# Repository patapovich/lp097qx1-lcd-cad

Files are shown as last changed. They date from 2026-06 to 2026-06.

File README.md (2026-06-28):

# LP097QX1-SPC1 — LCD mechanical CAD reference

Mounting/mechanical geometry for the **LG Display LP097QX1-SPC1** 9.7" 2048×1536 LCD
panel (as used in iPad 3/4), extracted from the datasheet **FRONT VIEW** drawing for
designing cases, bezels and mounts.

Geometry was **re-traced from a colour-cleaned render** of the FRONT VIEW: the
datasheet page is rasterized and every non-geometry marking (dimension lines,
dash-dot centerlines, green active-area reference, page header) is stripped *by
colour*, leaving only the black/grey object outline. The outline, 4 lug ears and
holes are then traced from that clean image and self-calibrated to the
167.12 × 208.88 outline. Hole centers cross-check against an independent
dimension-line calibration to **< 0.1 mm**.

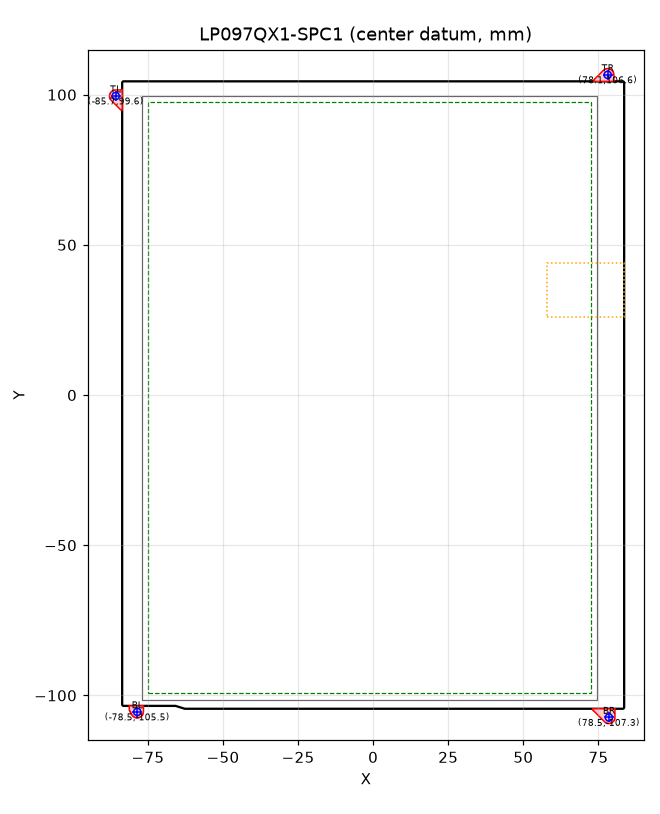
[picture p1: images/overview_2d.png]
2D overview


## Key dimensions (mm)

Datum = module-outline **center**, X → right, Y → up (front view as drawn).

| feature | size (W × H) | center offset | notes |
|---|---|---|---|
| Module outline | 167.12 × 208.88 (±0.5) | (0, 0) | thickness **2.60 max**; corners **R0.5**; **bottom-left non-square**: bottom edge raised to Y=−103.48 for X∈[−83.56,−65.8], ramps to full bottom (−104.44) by X=−62.7 |
| Bezel / polarizer | 151.608 × 201.01 | (−1.27, −0.86) | visible glass window |
| Active area | 147.456 × 196.608 | (−1.30, −0.89) | **not centered** |

### 4 mounting-lug holes — ⌀2.4 mm

| lug | X | Y | ear |
|---|---|---|---|
| TL | −85.71 | +99.55 | teardrop, points **left** (hole outside left edge) |
| TR | +78.07 | +106.59 | gusset, points **up** (hole outside top edge) |
| BL | −78.55 | −105.50 | teardrop, points **down** |
| BR | +78.48 | −107.34 | teardrop, points **down** |

> ⚠️ The lug layout is **asymmetric** (not a mirror set). Lugs protrude 3–5 mm past the
> 167.12 × 208.88 outline — your case must clear them.

**Z plane:** all 4 ears sit on the **front** (screen) face, Z 2.30–2.60 (thin 0.30 mm tabs).
The **rear FPC connector** is a keep-out boss on the **right long edge** (Y ≈ +26..+44),
protruding **~1.2 mm behind** the rear face (Z −1.20..0) — footprint approximate.

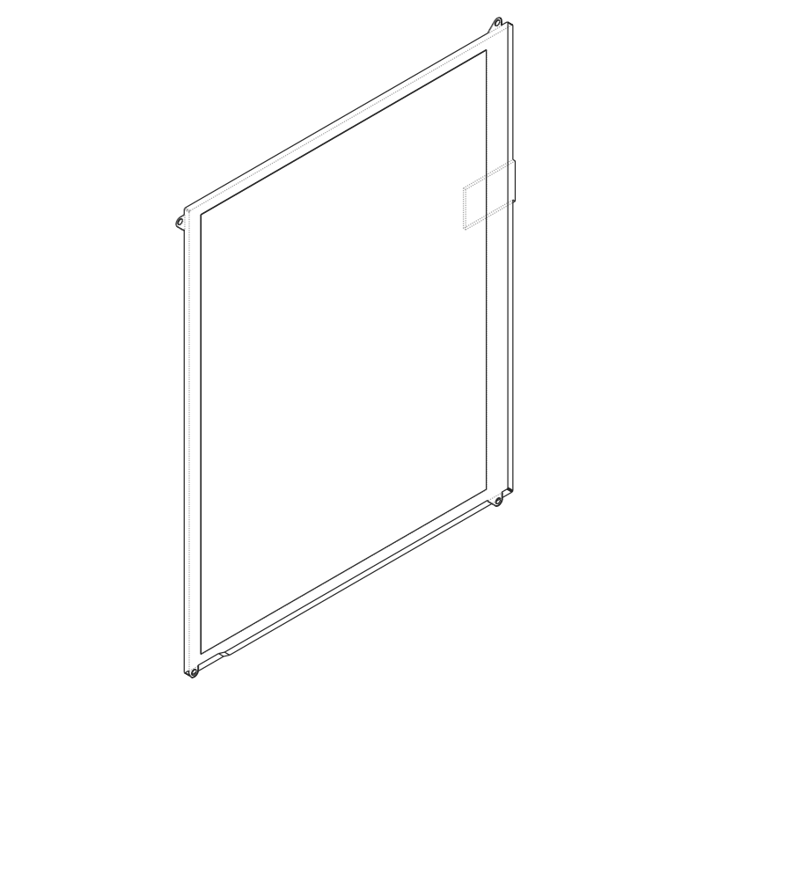
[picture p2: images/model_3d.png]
3D model


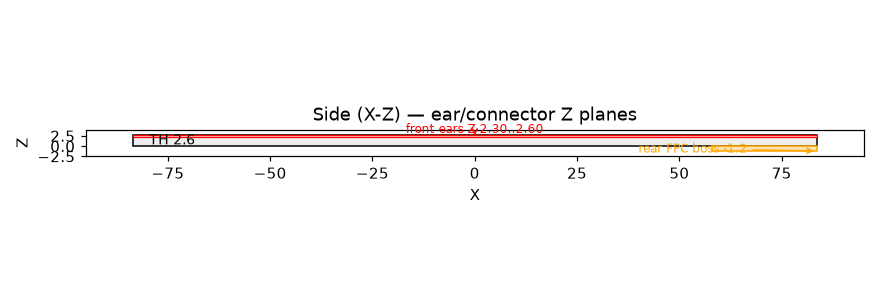
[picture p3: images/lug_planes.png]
lug planes


## Files

| file | description |
|---|---|
| `lcd_panel.step` | 3D solid: body + exact teardrop/gusset lug ears + ⌀2.4 holes + active-area pocket |
| `lcd_panel.stl` | mesh version of the above |
| `lcd_panel.scad` | parametric OpenSCAD source (all dims as variables) |
| `lcd_centerdatum.dxf` | 2D top view, origin = outline center, Y up |
| `lcd_cornerdatum.dxf` | 2D top view, origin = outline top-left, Y down (drawing convention) |
| `lcd_sideprofile.dxf` | side (Z) section: thickness 2.60, lug front plane, active recess |
| `lcd_lugs.csv` | hole coordinates, both datums |
| `lcd_reference.txt` | full numeric reference |
| `geometry.json` | **single source of truth** — clean-traced outline, ears, holes, bezel, Z, connector |
| `build_step.py` | builds the STEP/STL from `geometry.json` (needs cadquery) |
| `make_clean.py` | strips markings by colour + rasterizes the clean render |
| `trace2..6.py`, `geom.py` | trace pipeline (silhouette → edges → ears → holes → `geometry.json`) |
| `make_outputs.py` | regenerates the DXF/SCAD/CSV/reference/images |
| `verify.py` | overlays `geometry.json` back on the clean render |
| `bracket_top.step` / `.stl` | top photo-frame mounting bracket (3D print) |
| `bracket_bottom.step` / `.stl` | bottom photo-frame mounting bracket (3D print) |
| `bracket_top_thin.stl` / `bracket_bottom_thin.stl` | 5 mm-thick test-print variants (same XY/fit) |
| `build_brackets.py` | builds the two brackets from `geometry.json` + frame params (cadquery) |
| `brackets.scad` | parametric OpenSCAD source for the brackets |
| `verify_brackets.py` | assembly + side-section check images for the brackets |
| `passepartout.dxf` | mat cut lines (BOARD / WINDOW_SCREEN / WINDOW_GLASS layers) |
| `passepartout.py` | builds the mat drawing + DXF (180×240, 45° bevel window = screen) |
| `LP097QX1-SPC1.pdf` | source datasheet (© LG Display) |

DXF layers: `OUTLINE`, `BEZEL`, `ACTIVE`, `HOLES`, `HOLE_CENTERS`, `EARS`, `CONNECTOR`.

### Lug ear shapes
Traced silhouettes (red) + ⌀2.4 holes (green) over the colour-cleaned drawing:

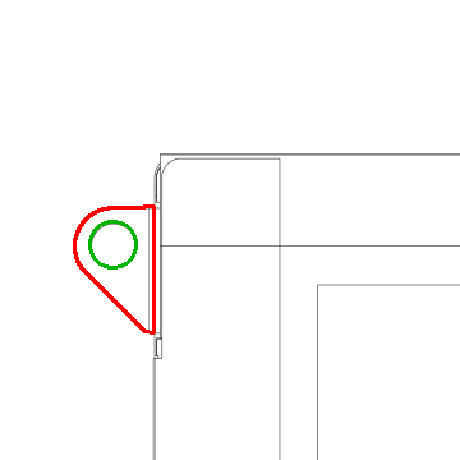
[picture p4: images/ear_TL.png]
ear TL
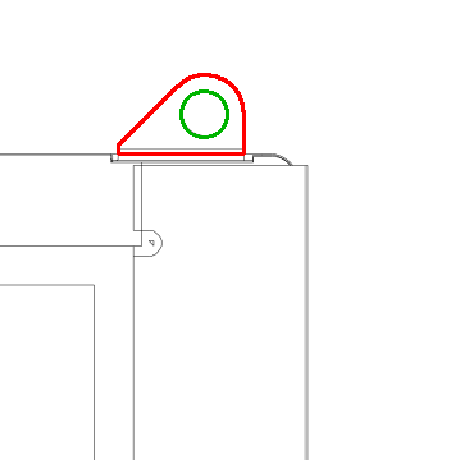
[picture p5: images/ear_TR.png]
ear TR
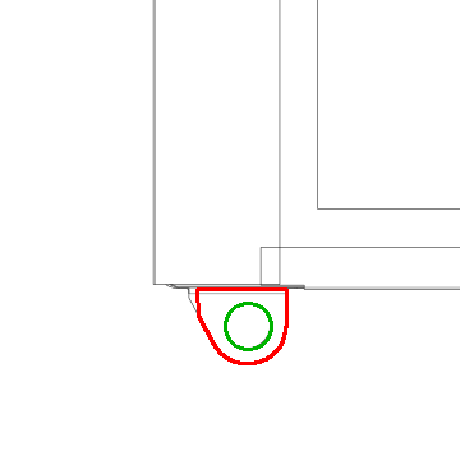
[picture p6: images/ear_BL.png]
ear BL
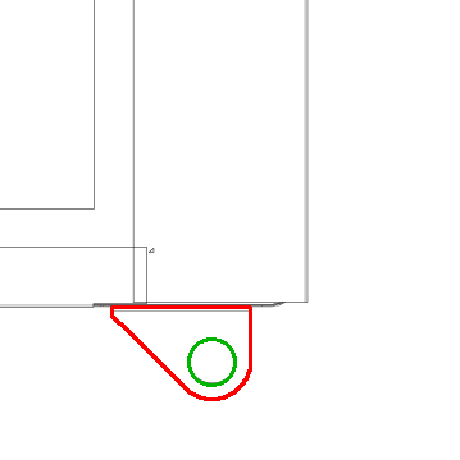
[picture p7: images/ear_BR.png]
ear BR
   

Lugs are **thin flat sheet-metal tabs (0.30 mm)** — not full-thickness — all on the
**front** (screen-side) face.

## Regenerate the 3D model

```bash
python3 -m venv cqenv
cqenv/bin/pip install cadquery cairosvg opencv-python-headless scipy
cqenv/bin/python build_step.py      # geometry.json -> lcd_panel.step + lcd_panel.stl
cqenv/bin/python make_outputs.py    # -> DXF / SCAD / CSV / reference / images
```

Re-trace from the PDF: `make_clean.py` → `trace2..6.py` → `geom.py` (writes `geometry.json`),
then `verify.py` overlays the result on the clean render. Or render the parametric source with
OpenSCAD: `openscad -o lcd_panel.stl lcd_panel.scad`.

## Photo-frame mounting brackets

Two **3D-printable back-press brackets** that hold the panel **centered in a photo frame** whose
inner cavity is **182 (W) × 242 (H) mm**. They sit on the panel's **short sides** (top + bottom),
friction-fit between the frame side walls. There is **no lip in front of the panel** — the screen
sits **flat on the frame glass**; the panel slides into a **2.75 mm slot** (2.60 LCD + 0.15) with the
rear shelf **behind** it, and the frame backing pushes the bracket so the shelf presses the LCD onto
the glass.

They **center the VIEW (active) area, not the outline.** The active area is offset from the
outline center by (−1.30, −0.89), so the panel is shifted (+1.30, +0.89) and the brackets are
sized to suit — the image lands in the frame center.

| | value |
|---|---|
| Frame inner cavity | 182 × 242 mm |
| Top-bracket gap (Y-depth) | **15.67 mm** |
| Bottom-bracket gap (Y-depth) | **17.45 mm** |
| Left / right gap (open, no bracket) | 8.74 / 6.14 mm |
| Bracket length (X, friction) | 181.8 mm (182 − 0.2) |
| Total thickness (Z) | 15.0 mm (screen on glass; rear shelf 2.75 → 15) |
| Panel slot (Z) | 2.75 mm = 2.60 LCD + 0.15 clearance; shelf sits **behind** the LCD |
| Rear shelf overhang onto border | 3.0 mm (clear of the active area) |

Check: 15.67 + 208.88 + 17.45 = 242.0 ✓. The lug ears are on the LCD **front** (recessed ~0.25 mm),
so each bracket's **ear-clearance pockets are cut on the front (glass) face** (top: TL+TR, bottom:
BL+BR). This **shape-keys** the part — it only seats with the ears in the front pockets (glass side),
which keeps the rear shelf behind the LCD, pressing it **from behind onto the glass**. The two
brackets are **different parts** (gaps and ear pockets differ).

**Thin test-print variants** (`bracket_top_thin.stl`, `bracket_bottom_thin.stl`, Z = 5 mm) have the
same XY/fit/slot/ear pockets — print one fast/cheap to check fit + orientation before the full 15 mm
part. Ear pockets are placed at each tab's **actual** position (the asymmetric layout: TL left-edge,
TR top-edge, BL/BR bottom-edge), with **1.5 mm clearance** all round — see the coverage check below.
Pockets + outline are **`MIRROR_X`-handed to match the physical panel** (see Handedness above).

Each bracket's total depth into the cavity is the end-gap **plus** the 3 mm shelf overhang behind the
LCD border (top 15.67+3.0, bottom 17.45+3.0), all behind the screen — the active area stays clear.

**Handedness:** the datasheet **FRONT VIEW is mirrored left-right vs the physical panel**, so the
brackets are built with **`MIRROR_X=True`** to match the real part. Front view (screen toward you):
the prominent angled lug is at the **top-right**, the single up-poking lug at the top-left, two lugs
on the bottom edge. (Set `MIRROR_X=False` to follow the raw datasheet handedness instead.)

### Orientation (important)
The part is nearly symmetric front-to-back, so it has an explicit key: the flat rear face is
**debossed "BACK"**. That face goes against the **frame backing**; the opposite face — with the open
slot + ear pockets — goes against the **glass / LCD**. The rear shelf then sits behind the LCD and the
frame backing presses it **from behind onto the glass**.

- **Print** the flat **"BACK"** face on the bed (slot + pockets facing up) → the rear-shelf overhang
  prints support-free. The bed face is the frame-backing face.
- **Assemble:** frame face-down on the glass; LCD in screen-first (rests on glass); push each bracket
  into its end gap **pocket/open face toward the glass** (the "BACK" deboss faces out, toward you) so
  the rear shelf sits behind the LCD edge; close the frame back — its clamping seats the LCD on the glass.

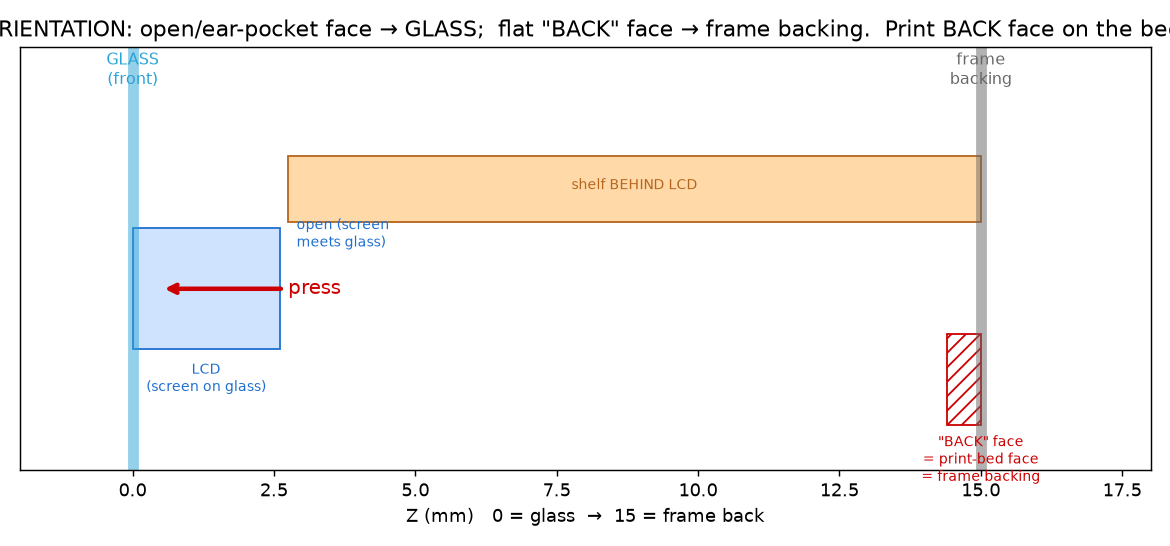
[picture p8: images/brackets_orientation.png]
bracket orientation

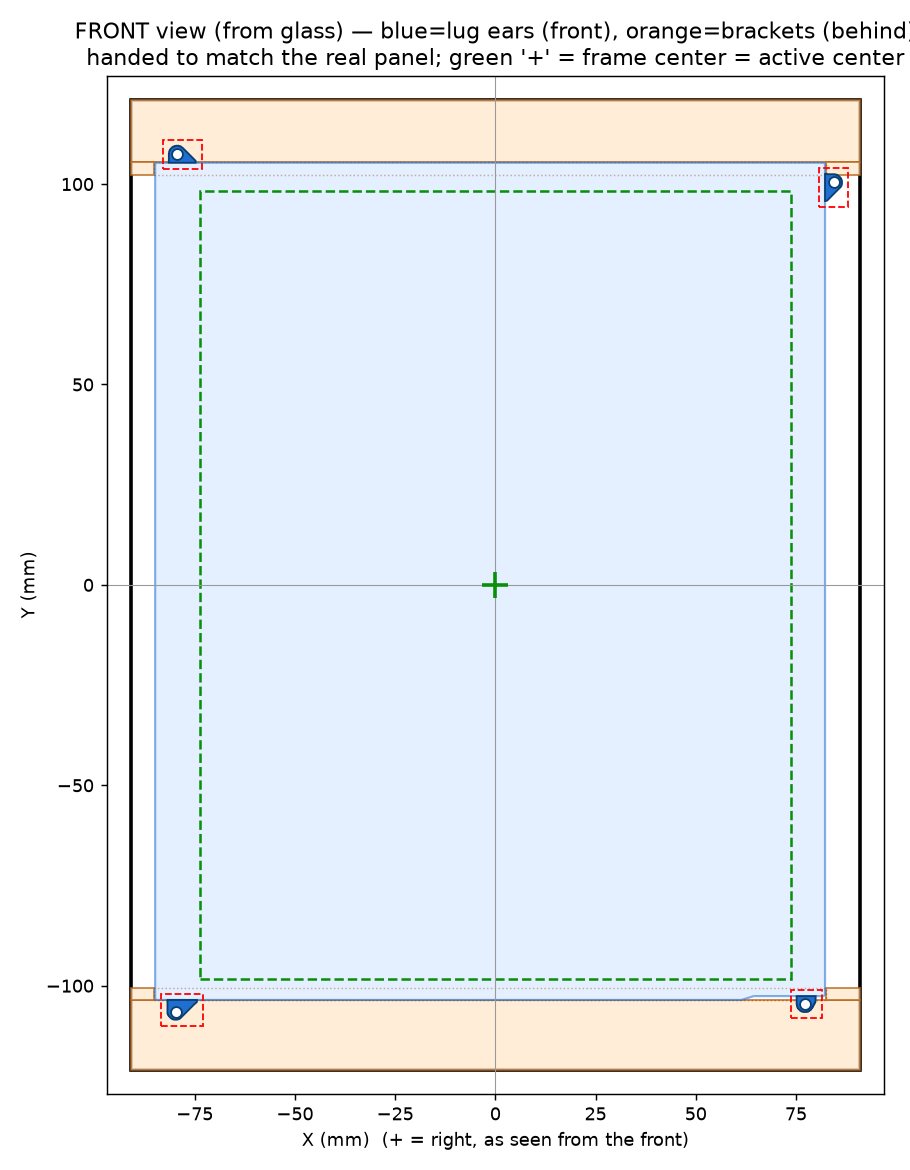
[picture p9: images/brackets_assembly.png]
bracket assembly

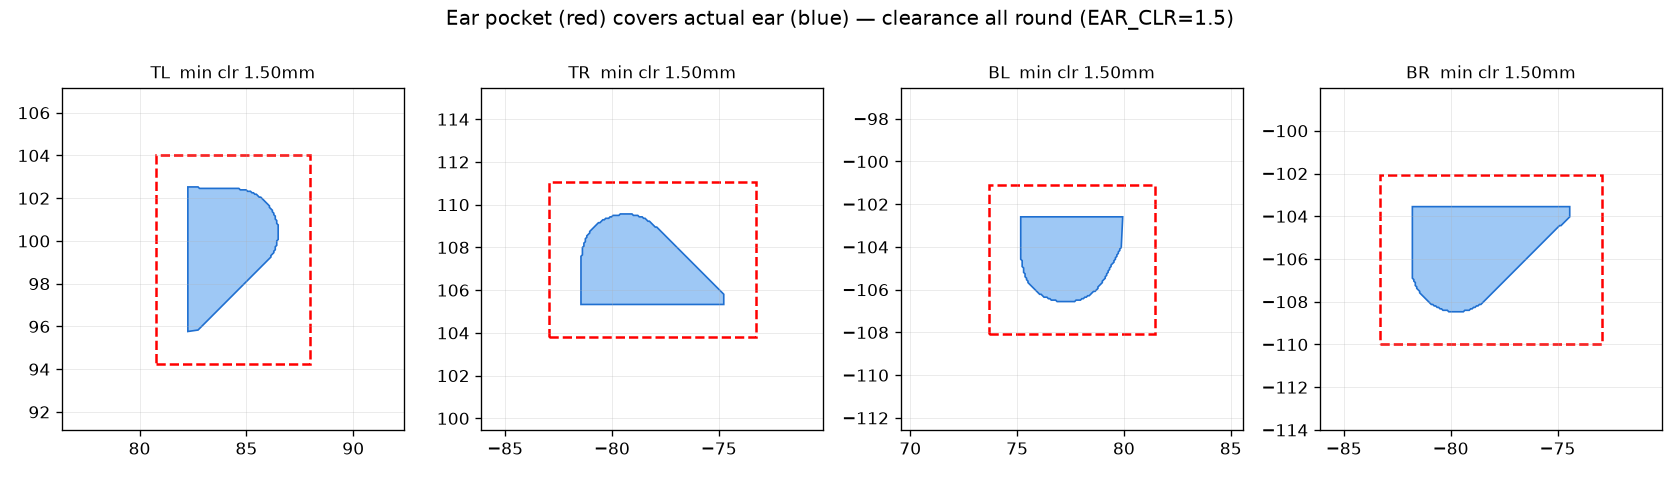
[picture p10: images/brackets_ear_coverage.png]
ear pocket coverage

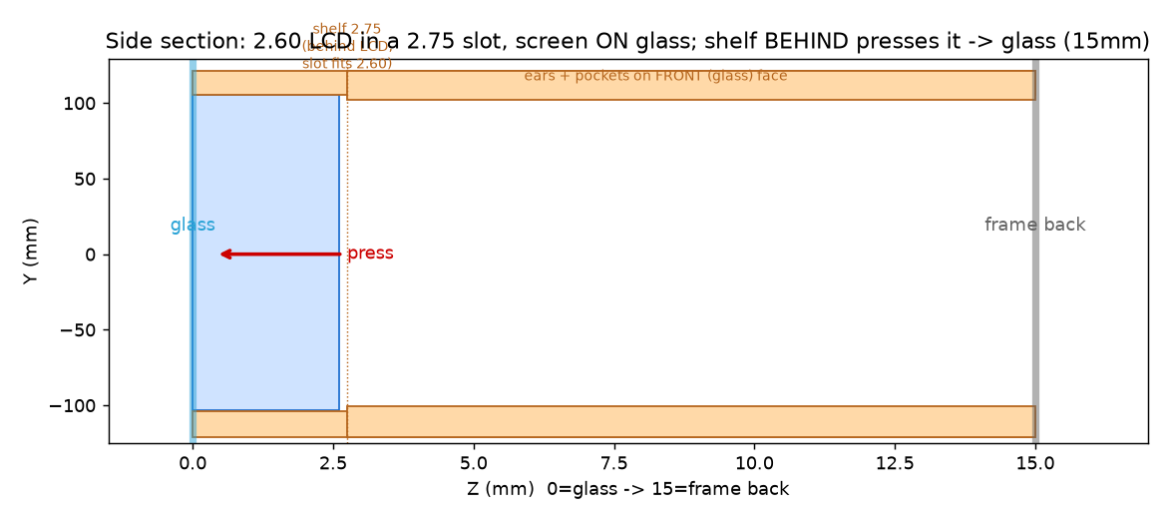
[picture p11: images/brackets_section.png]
bracket section


**Print:** PLA/PETG, lay flat — no supports. **Tune the fit** at the top of `build_brackets.py` /
`brackets.scad`: `FIT_CLR` (frame friction), `SEAT_CLR`/`POCKET_CLR` (panel play), `SLOT_CLR`
(panel slot Z — lower for tighter glass contact, raise if the LCD is tight), `EAR_Z` (front ear-pocket
depth), `LIP_Y` (rear-shelf grip), `MIRROR_X` (flip handedness), `LABEL` (the "BACK" deboss).
`VIEW_CENTER=False` centers the outline instead (equal 16.56 mm gaps). (Assembly + print orientation
are covered in **Orientation** above.)

```bash
cqenv/bin/python build_brackets.py     # -> bracket_top/bottom .step + .stl
cqenv/bin/python verify_brackets.py    # -> images/brackets_assembly.png + brackets_section.png
# or parametric: openscad -o bracket_top.stl -D 'part="top"' brackets.scad
```

## Passe-partout (mat window)

A **180 × 240 × 1.4 mm** mat with a centred **45° bevel** window that reveals only the **active
screen** (147.456 × 196.608). The brackets centre the active area at the frame centre, so the window
is **centred** in the board (symmetric — equal borders).

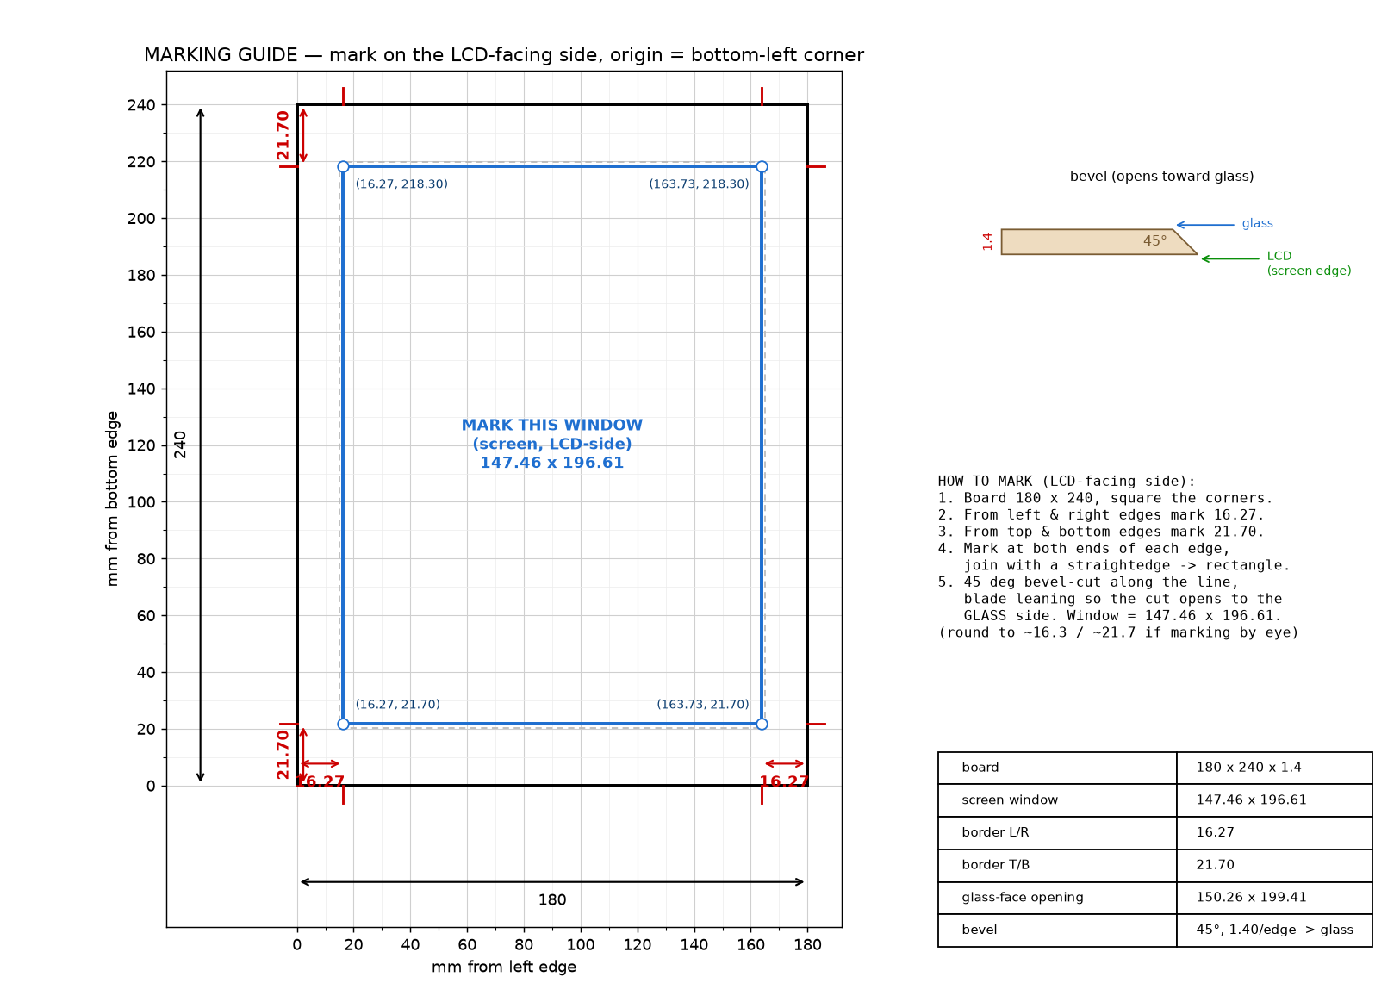
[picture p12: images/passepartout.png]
passe-partout


**Bevel opens toward the glass/viewer** — the screen-sized (limiting) edge is on the **LCD-facing
(back) face**, sitting right at the screen plane; the 45° bevel flares **1.4 mm/edge toward the glass**
so the white bevel faces you.

| feature | mm |
|---|---|
| Board (outer) | 180 × 240 × 1.4 |
| **Screen window** (visible crop, on LCD-side face) | **147.46 × 196.61** (= active screen) |
| LCD-face border — L/R, T/B | **16.27**, **21.70** |
| Glass-face opening (larger, bevel mouth) | 150.26 × 199.41 |
| Glass-face border — L/R, T/B | 14.87, 20.30 |
| Bevel | 45°, run 1.40 mm/edge, opens toward glass |

**Hand-marking** (`images/passepartout.png` is a ruler/pencil guide): on the LCD-facing side, from
**each** edge measure **16.27 mm** (left/right) and **21.70 mm** (top/bottom), mark at both ends of
every edge, join with a straightedge → the 147.46 × 196.61 rectangle, then 45° bevel-cut. Window
corners from the bottom-left corner: **(16.27, 21.70)**, **(163.73, 21.70)**, **(16.27, 218.30)**,
**(163.73, 218.30)**.

- The **screen-sized opening is on the LCD side** (147.46 × 196.61) and crops exactly to the screen;
  the bevel widens to **150.26 × 199.41** at the glass face. White bevel faces the viewer.
- Manual cutter: cut so the **small (screen-sized) opening is on the LCD-facing side**; the 45° bevel
  mouth opens toward the glass. `WINDOW_SCREEN` in the DXF is the crop edge, `WINDOW_GLASS` the mouth.
- Set `BEVEL_TOWARD="lcd"` in `passepartout.py` for the standard picture-mat direction (screen edge on
  the glass face instead). `OVERLAP=1.0` covers ~1 mm of the screen edge (no bezel sliver).
- Board 180 × 240 sits in the 182 × 242 frame with ~1 mm clearance/side — keep it centred so the
  window lines up with the (centred) screen.

## Accuracy

- Outline = datasheet nominal (167.12 × 208.88); model self-calibrated to it.
- Hole centers: ≈ ±0.05 mm relative, ≈ ±0.1 mm vs the independent dimension-line calibration.
- Ear silhouettes are traced from the clean render (≈ ±0.1 mm, drawing-scale limit).
- Datasheet's own outline tolerance is ±0.5 mm.
- Lug ears are **thin flat sheet-metal tabs (0.30 mm)**, all on the **front** (screen) face
  (Z 2.30..2.60), confirmed against the physical part.

## Source

Datasheet: LG Display LP097QX1-SPC1, mirrored at
<http://mikesmods.com/mm-wp/wp-content/uploads/2013/04/LP097QX1-SPC1.pdf>
(FRONT VIEW, printed page 16/28). The PDF is © LG Display, included here for reference.

Extracted geometry and CAD files in this repo are provided as-is, no warranty — verify
against the datasheet before manufacturing.

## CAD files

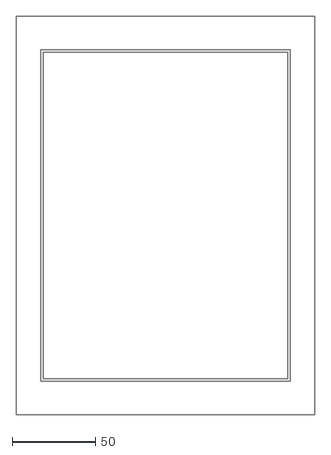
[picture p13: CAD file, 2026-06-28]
passepartout.dxf
180.0 x 240.0

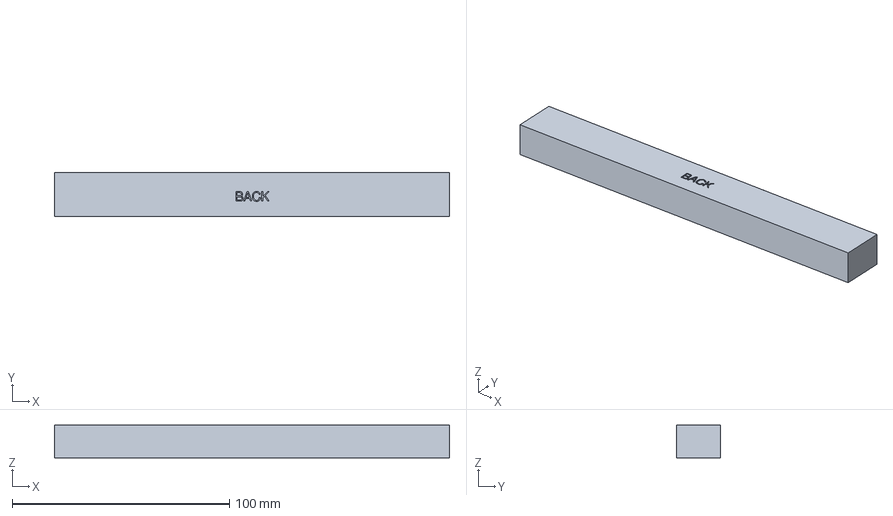
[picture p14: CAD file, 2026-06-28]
bracket_bottom.step
181.8 x 20.5 x 15.0 mm

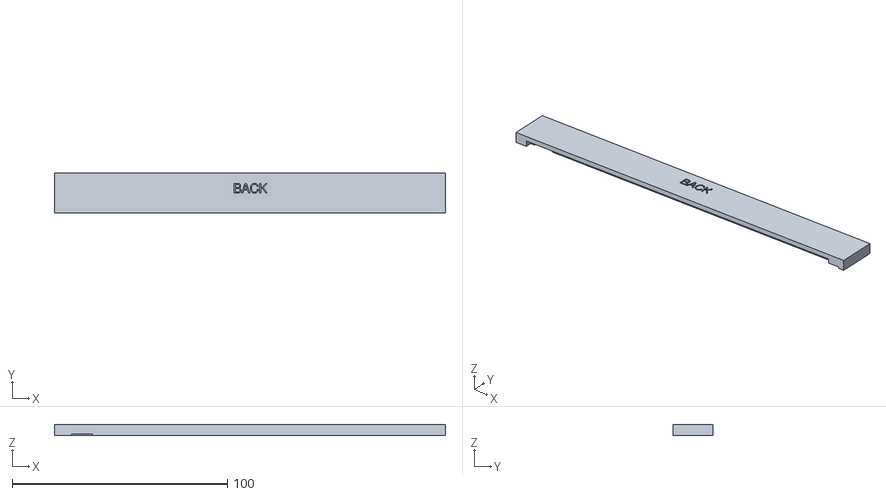
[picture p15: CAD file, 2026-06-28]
bracket_top_thin.stl
181.8 x 18.7 x 5.00

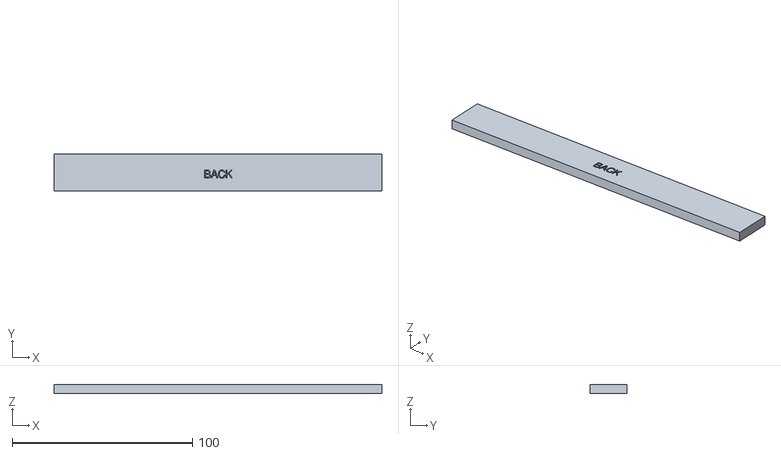
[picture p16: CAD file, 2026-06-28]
bracket_bottom_thin.stl
181.8 x 20.4 x 5.00

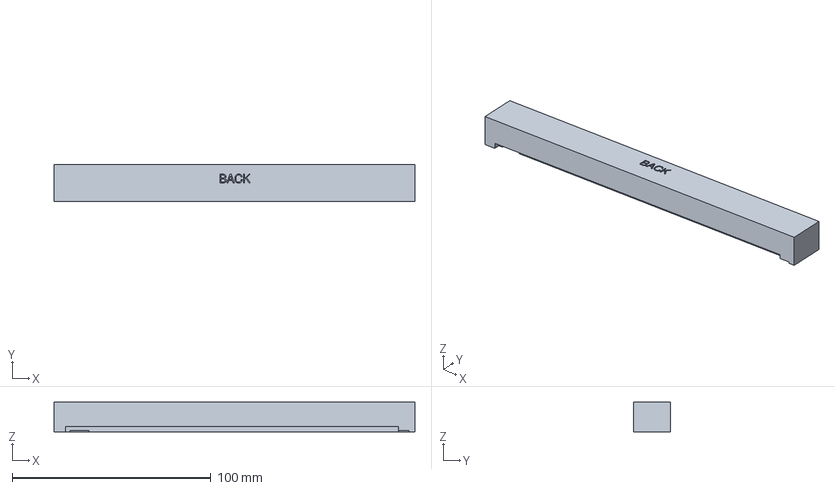
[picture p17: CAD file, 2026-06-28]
bracket_top.step
181.8 x 18.7 x 15.0 mm

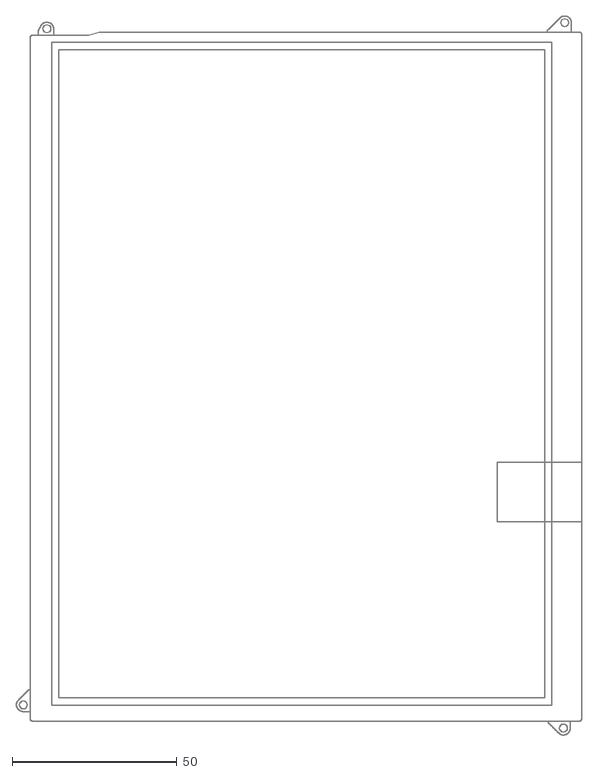
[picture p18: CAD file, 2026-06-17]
lcd_cornerdatum.dxf
171.3 x 218.0

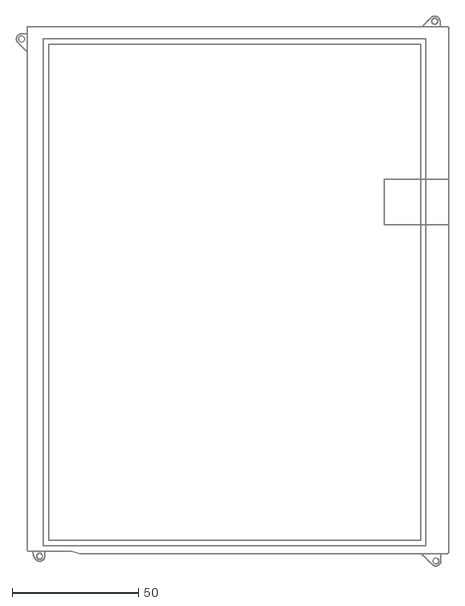
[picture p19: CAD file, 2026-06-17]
lcd_centerdatum.dxf
171.3 x 218.0

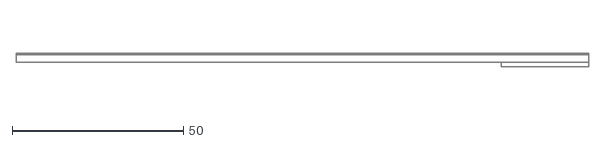
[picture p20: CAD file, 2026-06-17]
lcd_sideprofile.dxf
167.1 x 3.80

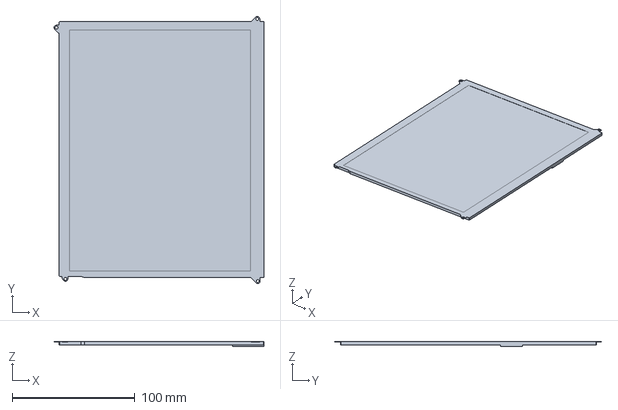
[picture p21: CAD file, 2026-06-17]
lcd_panel.step
171.3 x 218.0 x 3.80 mm

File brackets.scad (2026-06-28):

// Photo-frame brackets for the LP097QX1-SPC1 LCD — parametric OpenSCAD twin of build_brackets.py
// Two L / back-press brackets on the panel's SHORT sides (top + bottom). Friction-fit in the frame.
// No front lip: the screen sits flat on the glass; the panel slot = panel_th + slot_clr and the rear
// shelf sits BEHIND the panel, so the frame backing pushes the bracket -> LCD onto the glass (push
// from behind). Centers the VIEW (active) area. Lug ears are on the LCD FRONT (recessed ~0.25mm) ->
// shallow ear pockets on the front face, which shape-keys the part (only seats ears-toward-glass).
// Frame coords: origin = frame center, X right, Y up, Z=0 glass -> +Z into cavity.
//   render: openscad -o bracket_top.stl -D part=\"top\" brackets.scad
//   thin test print: add -D total_z=5
part = "both";        // "both" | "top" | "bottom"

/* ---- frame + panel ---- */
frame_w = 182;        // photo-frame inner width
frame_h = 242;        // photo-frame inner height
panel_w = 167.12;     // LCD outline
panel_h = 208.88;
panel_th = 2.60;      // LCD thickness
act_cx  = -1.30;      // active-area offset on the outline
act_cy  = -0.89;
view_center = true;   // center active area (true) or outline (false)

/* ---- bracket / fit ---- */
total_z = 15.0;       // bracket thickness (glass -> frame backing) = cavity depth
slot_clr = 0.15;      // Z clearance: panel slot = panel_th + slot_clr (shelf sits BEHIND the panel)
lip_y   = 3.0;        // rear-shelf overhang onto the panel border
fit_clr = 0.2;        // friction: length = frame_w - fit_clr
seat_clr = 0.1;       // play, panel edge vs channel web
pocket_clr = 0.3;     // play, panel corner vs X end-stops
ear_clr = 1.5;        // margin around an ear pocket
ear_on_back = false;  // lugs on the LCD FRONT (recessed ~0.25mm) -> clear them on the front face
ear_z   = 0.7;        // shallow front pocket depth (clears the ~0.25..0.55 recessed front ear tabs)
mirror_x = true;      // datasheet front view is mirrored vs the physical panel -> flip X to match real part
label = true;         // deboss "BACK" on the flat rear face = orientation key
label_text = "BACK";  // this face -> frame backing; opposite (slot) face -> glass
label_h = 6.0;        // text height
label_depth = 0.6;    // deboss depth
gap     = 0.001;      // tiny boolean overlap

/* ---- ear spans [xmin,xmax,ymin,ymax] from geometry.json ---- */
ear_TL = [-87.787, -83.560,  94.874, 101.639];
ear_TR = [ 73.469,  80.151, 104.440, 108.676];
ear_BL = [-81.242, -76.469,-107.446,-103.480];
ear_BR = [ 73.128,  80.492,-109.360,-104.440];

shift_x = (view_center ? -act_cx : 0) * (mirror_x ? -1 : 1);   // +1.30 (negated if mirror_x)
shift_y = view_center ? -act_cy : 0;   // +0.89
hw = panel_w/2; hh = panel_h/2;
hfw = frame_w/2; hfh = frame_h/2;
lx = (frame_w - fit_clr)/2;
flange_z0 = panel_th + slot_clr;   // rear shelf front face (2.75) - behind the panel

module boxc(x0,x1,y0,y1,z0,z1) translate([x0,y0,z0]) cube([x1-x0,y1-y0,z1-z0]);

module bracket(side) {                 // side = +1 top, -1 bottom
  edgeY     = side*(hh + side*shift_y);
  webInnerY = edgeY + side*seat_clr;
  lipInnerY = edgeY - side*lip_y;
  wallY     = side*hfh;
  stopL = shift_x - hw - pocket_clr;
  stopR = shift_x + hw + pocket_clr;
  wlo = min(webInnerY,wallY); whi = max(webInnerY,wallY);
  llo = min(lipInnerY,webInnerY); lhi = max(lipInnerY,webInnerY);
  ears = side>0 ? [ear_TL,ear_TR] : [ear_BL,ear_BR];
  difference() {
    union() {
      boxc(-lx, lx, wlo, whi, 0, total_z);              // web / gap filler (front on glass)
      boxc(-lx, stopL, llo, lhi, 0, total_z);           // end stop L
      boxc(stopR, lx, llo, lhi, 0, total_z);            // end stop R
      boxc(stopL, stopR, llo, lhi, flange_z0, total_z); // rear shelf (behind the panel)
    }
    for (e = ears) {                                    // ear pockets at the tab's actual frame bbox
      ex0 = (mirror_x ? -e[1] : e[0]) + shift_x;        // ear bbox in frame X (panel shift, mirror-aware)
      ex1 = (mirror_x ? -e[0] : e[1]) + shift_x;
      ay0 = e[2] + shift_y; ay1 = e[3] + shift_y;       // ear bbox in frame Y
      z0 = ear_on_back ? (panel_th-0.6) : -gap;
      z1 = ear_on_back ? total_z+gap : ear_z;
      boxc(ex0-ear_clr, ex1+ear_clr, ay0-ear_clr, ay1+ear_clr, z0, z1);
    }
    if (label)                                          // deboss "BACK" into the flat rear face
      translate([0, (webInnerY+wallY)/2, total_z-label_depth])
        linear_extrude(label_depth+gap)
          text(label_text, size=label_h, halign="center", valign="center");
  }
}

if (part == "top")    bracket(1);
if (part == "bottom") bracket(-1);
if (part == "both") { bracket(1); bracket(-1); }

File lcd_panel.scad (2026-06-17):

// LP097QX1-SPC1 LCD module - CLEAN-traced geometry (center datum, mm, Y up).
// Body=traced outline (full 2.6mm). Ears=thin FRONT tabs (0.3mm). Rear FPC boss RIGHT edge.
OUT_W=167.12; OUT_H=208.88; TH=2.6; LUG_T=0.3; HOLE_D=2.4;
ACT_W=147.456; ACT_H=196.608; ACT_CX=-1.3; ACT_CY=-0.89; ACT_D=0.20;
CONN=[58.0,83.56,26.0,44.0]; CONN_D=1.2;
OUTLINE=[[83.560,103.940],[83.547,104.051],[83.510,104.157],[83.451,104.252],[83.372,104.331],[83.277,104.390],[83.171,104.427],[83.060,104.440],[-83.060,104.440],[-83.171,104.427],[-83.277,104.390],[-83.372,104.331],[-83.451,104.252],[-83.510,104.157],[-83.547,104.051],[-83.560,103.940],[-83.560,-102.980],[-83.547,-103.091],[-83.510,-103.197],[-83.451,-103.292],[-83.372,-103.371],[-83.277,-103.430],[-83.171,-103.467],[-83.060,-103.480],[-65.800,-103.480],[-62.700,-104.440],[83.060,-104.440],[83.171,-104.427],[83.277,-104.390],[83.372,-104.331],[83.451,-104.252],[83.510,-104.157],[83.547,-104.051],[83.560,-103.940]];
HOLES=[[-85.708,99.555],[-78.548,-105.499],[78.480,-107.344],[78.071,106.592]];
EARS=[
  [[-83.560,101.639],[-84.037,101.639],[-84.105,101.570],[-84.174,101.570],[-84.242,101.570],[-84.310,101.570],[-84.378,101.570],[-84.446,101.570],[-84.515,101.570],[-84.583,101.570],[-84.651,101.570],[-84.719,101.570],[-84.787,101.570],[-84.856,101.570],[-84.924,101.570],[-84.992,101.570],[-85.060,101.570],[-85.128,101.570],[-85.196,101.570],[-85.265,101.570],[-85.333,101.570],[-85.401,101.570],[-85.469,101.570],[-85.537,101.570],[-85.606,101.570],[-85.674,101.570],[-85.742,101.570],[-85.810,101.570],[-85.878,101.570],[-85.946,101.570],[-86.015,101.502],[-86.083,101.502],[-86.151,101.502],[-86.219,101.502],[-86.287,101.502],[-86.356,101.434],[-86.424,101.434],[-86.492,101.434],[-86.560,101.365],[-86.628,101.365],[-86.696,101.297],[-86.765,101.297],[-86.833,101.229],[-86.901,101.160],[-86.969,101.160],[-87.037,101.092],[-87.106,101.024],[-87.174,100.955],[-87.242,100.887],[-87.310,100.819],[-87.378,100.750],[-87.378,100.682],[-87.447,100.614],[-87.515,100.545],[-87.515,100.477],[-87.583,100.409],[-87.583,100.340],[-87.651,100.272],[-87.651,100.204],[-87.651,100.135],[-87.719,100.067],[-87.719,99.999],[-87.719,99.930],[-87.787,99.862],[-87.787,99.794],[-87.787,99.725],[-87.787,99.657],[-87.787,99.589],[-87.787,99.520],[-87.787,99.452],[-87.787,99.384],[-87.787,99.315],[-87.787,99.247],[-87.787,99.179],[-87.719,99.110],[-87.719,99.042],[-87.719,98.974],[-87.719,98.905],[-87.651,98.837],[-87.651,98.769],[-87.651,98.700],[-87.583,98.632],[-87.583,98.564],[-87.515,98.495],[-87.447,98.427],[-87.447,98.359],[-87.378,98.290],[-87.310,98.222],[-87.242,98.154],[-87.174,98.085],[-87.106,98.017],[-87.037,97.949],[-86.969,97.880],[-86.901,97.812],[-86.833,97.744],[-86.765,97.675],[-86.696,97.607],[-86.628,97.539],[-86.560,97.471],[-86.492,97.402],[-86.424,97.334],[-86.356,97.266],[-86.287,97.197],[-86.219,97.129],[-86.151,97.061],[-86.083,96.992],[-86.015,96.924],[-85.946,96.856],[-85.878,96.787],[-85.810,96.719],[-85.742,96.651],[-85.674,96.582],[-85.606,96.514],[-85.537,96.446],[-85.469,96.377],[-85.401,96.309],[-85.333,96.241],[-85.265,96.172],[-85.196,96.104],[-85.128,96.036],[-85.060,95.967],[-84.992,95.899],[-84.924,95.831],[-84.856,95.762],[-84.787,95.694],[-84.719,95.626],[-84.651,95.557],[-84.583,95.489],[-84.515,95.421],[-84.446,95.352],[-84.378,95.284],[-84.310,95.216],[-84.242,95.147],[-84.174,95.079],[-84.105,95.011],[-84.037,94.942],[-83.560,94.874]],
  [[-81.242,-103.480],[-81.174,-104.918],[-81.105,-104.987],[-81.105,-105.055],[-81.037,-105.123],[-81.037,-105.192],[-80.969,-105.260],[-80.969,-105.328],[-80.901,-105.397],[-80.901,-105.465],[-80.833,-105.533],[-80.833,-105.602],[-80.764,-105.670],[-80.696,-105.738],[-80.696,-105.807],[-80.628,-105.875],[-80.628,-105.943],[-80.560,-106.012],[-80.560,-106.080],[-80.492,-106.148],[-80.492,-106.217],[-80.424,-106.285],[-80.424,-106.353],[-80.355,-106.422],[-80.287,-106.490],[-80.287,-106.558],[-80.219,-106.627],[-80.151,-106.695],[-80.083,-106.763],[-80.083,-106.831],[-80.014,-106.900],[-79.946,-106.968],[-79.878,-106.968],[-79.810,-107.036],[-79.742,-107.105],[-79.673,-107.173],[-79.605,-107.173],[-79.537,-107.241],[-79.469,-107.241],[-79.401,-107.310],[-79.333,-107.310],[-79.264,-107.378],[-79.196,-107.378],[-79.128,-107.378],[-79.060,-107.378],[-78.992,-107.446],[-78.923,-107.446],[-78.855,-107.446],[-78.787,-107.446],[-78.719,-107.446],[-78.651,-107.446],[-78.583,-107.446],[-78.514,-107.446],[-78.446,-107.446],[-78.378,-107.446],[-78.310,-107.446],[-78.242,-107.446],[-78.173,-107.446],[-78.105,-107.378],[-78.037,-107.378],[-77.969,-107.378],[-77.901,-107.378],[-77.833,-107.310],[-77.764,-107.310],[-77.696,-107.241],[-77.628,-107.241],[-77.560,-107.241],[-77.492,-107.173],[-77.423,-107.105],[-77.355,-107.105],[-77.287,-107.036],[-77.219,-106.968],[-77.151,-106.900],[-77.082,-106.831],[-77.014,-106.763],[-76.946,-106.695],[-76.878,-106.627],[-76.810,-106.558],[-76.810,-106.490],[-76.742,-106.422],[-76.742,-106.353],[-76.673,-106.285],[-76.673,-106.217],[-76.673,-106.148],[-76.605,-106.080],[-76.605,-106.012],[-76.605,-105.943],[-76.605,-105.875],[-76.537,-105.807],[-76.537,-105.738],[-76.537,-105.670],[-76.537,-105.602],[-76.537,-105.533],[-76.469,-105.465],[-76.469,-105.397],[-76.469,-105.328],[-76.469,-105.260],[-76.469,-105.192],[-76.469,-105.123],[-76.469,-105.055],[-76.469,-104.987],[-76.469,-104.918],[-76.469,-103.480]],
  [[73.128,-104.440],[73.128,-104.918],[73.196,-104.987],[73.264,-105.055],[73.332,-105.123],[73.401,-105.192],[73.469,-105.260],[73.537,-105.328],[73.605,-105.328],[73.673,-105.397],[73.741,-105.465],[73.810,-105.533],[73.878,-105.602],[73.946,-105.670],[74.014,-105.738],[74.082,-105.807],[74.151,-105.875],[74.219,-105.943],[74.287,-106.012],[74.355,-106.080],[74.423,-106.148],[74.491,-106.217],[74.560,-106.285],[74.628,-106.353],[74.696,-106.422],[74.764,-106.490],[74.832,-106.558],[74.901,-106.627],[74.969,-106.695],[75.037,-106.763],[75.105,-106.831],[75.173,-106.900],[75.242,-106.968],[75.310,-107.036],[75.378,-107.105],[75.446,-107.173],[75.514,-107.241],[75.582,-107.310],[75.651,-107.378],[75.719,-107.446],[75.787,-107.515],[75.855,-107.583],[75.923,-107.651],[75.992,-107.720],[76.060,-107.788],[76.128,-107.856],[76.196,-107.925],[76.264,-107.993],[76.332,-108.061],[76.401,-108.130],[76.469,-108.198],[76.537,-108.266],[76.605,-108.335],[76.673,-108.403],[76.742,-108.471],[76.810,-108.540],[76.878,-108.608],[76.946,-108.676],[77.014,-108.745],[77.082,-108.813],[77.151,-108.881],[77.219,-108.950],[77.287,-109.018],[77.355,-109.018],[77.423,-109.086],[77.492,-109.086],[77.560,-109.155],[77.628,-109.155],[77.696,-109.223],[77.764,-109.223],[77.833,-109.291],[77.901,-109.291],[77.969,-109.291],[78.037,-109.291],[78.105,-109.360],[78.173,-109.360],[78.242,-109.360],[78.310,-109.360],[78.378,-109.360],[78.446,-109.360],[78.514,-109.360],[78.583,-109.360],[78.651,-109.360],[78.719,-109.360],[78.787,-109.360],[78.855,-109.291],[78.923,-109.291],[78.992,-109.291],[79.060,-109.291],[79.128,-109.223],[79.196,-109.223],[79.264,-109.155],[79.333,-109.155],[79.401,-109.086],[79.469,-109.086],[79.537,-109.018],[79.605,-109.018],[79.673,-108.950],[79.742,-108.881],[79.810,-108.813],[79.878,-108.745],[79.946,-108.676],[80.014,-108.608],[80.083,-108.540],[80.151,-108.471],[80.151,-108.403],[80.219,-108.335],[80.287,-108.266],[80.287,-108.198],[80.355,-108.130],[80.355,-108.061],[80.355,-107.993],[80.424,-107.925],[80.424,-107.856],[80.492,-107.788],[80.492,-107.720],[80.492,-107.651],[80.492,-107.583],[80.492,-107.515],[80.492,-107.446],[80.492,-107.378],[80.492,-107.310],[80.492,-107.241],[80.492,-107.173],[80.492,-107.105],[80.492,-107.036],[80.492,-106.968],[80.492,-106.900],[80.492,-106.831],[80.492,-106.763],[80.492,-106.695],[80.492,-106.627],[80.492,-106.558],[80.492,-106.490],[80.492,-106.422],[80.492,-106.353],[80.492,-106.285],[80.492,-106.217],[80.492,-106.148],[80.492,-106.080],[80.492,-106.012],[80.492,-105.943],[80.492,-105.875],[80.492,-105.807],[80.492,-105.738],[80.492,-105.670],[80.492,-105.602],[80.492,-105.533],[80.492,-105.465],[80.492,-105.397],[80.492,-105.328],[80.492,-105.260],[80.492,-105.192],[80.492,-105.123],[80.492,-105.055],[80.492,-104.987],[80.492,-104.918],[80.492,-104.440]],
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

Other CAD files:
bracket_bottom.stl
bracket_top.stl
lcd_panel.stl

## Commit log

2026-06-16 LP097QX1-SPC1 LCD mechanical CAD reference
    Outline, bezel, active-area and 4 mounting-lug ears + holes extracted from
    the datasheet front-view vector drawing. Includes 2D DXF (center + corner
    datum), 3D STEP/STL, parametric OpenSCAD, CSV/text reference and build scripts.
    [lcd_centerdatum.dxf, lcd_cornerdatum.dxf, lcd_lugs.csv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]
2026-06-16 Lugs as thin sheet-metal tabs (0.30mm at rear) + tighter ear silhouettes
    - Measured rear-frame/lug gauge ~0.3mm from datasheet side/cross-section views;
    lugs now modelled as thin flat tabs on the rear face (Z 0..0.30) instead of full
    2.60mm blocks, fused to the body.
    - Re-traced ear outlines to the stroke centerline with sharper corners (closer match
    to the drawing). Updated STEP/STL/SCAD/DXF/reference/README + images.
    [lcd_centerdatum.dxf, lcd_cornerdatum.dxf, lcd_panel.scad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]
2026-06-17 Lug ears: per-face Z (TR/BR front, TL/BL rear)
    Datasheet side views show the ears split across both faces, not all at the rear.
    TR + BR sit on the FRONT/screen plane (Z 2.30..2.60); TL + BL on the REAR plane
    (Z 0..0.30). Updated build_step.py (FRONT_EARS map), lcd_panel.scad, reference,
    README + images (lug_planes close-ups).
    [lcd_panel.scad, lcd_panel.step, lcd_panel.stl]
2026-06-17 Re-verify all dims; lugs ALL on FRONT plane (Z 2.30-2.60)
    - Corrected lug Z-plane: all 4 ears on the FRONT (screen) face per the physical part
    (earlier per-face split was based on a retracted guess).
    - Re-verified every XY dimension vs the datasheet (outline/bezel/active/offset/holes/dia)
    and Z (thickness 2.60, lug 0.30, active recess 0.20).
    - Added lcd_sideprofile.dxf (side Z section documenting depth).
    - Regenerated STEP/STL/SCAD/DXF/CSV/reference/README + images; dropped dead intermediates.
    [lcd_panel.scad, lcd_panel.step, lcd_panel.stl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]
2026-06-17 Tighten lug silhouettes (remove base overlap from outline); refresh ear images
    Ear outlines now hug the drawing exactly (base at the panel edge, no 1mm overspill).
    _ears.json/DXF/SCAD use the clean outline; STEP adds a build-time base overlap only,
    so it still fuses to 1 solid. Regenerated ear_*.png, DXFs, SCAD, overview + 3D images.
    [lcd_centerdatum.dxf, lcd_cornerdatum.dxf, lcd_panel.scad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]
2026-06-17 Add rear FPC connector keep-out boss (right long edge)
    Connector on the RIGHT long edge (user-confirmed), upper-third (Y +26..+44), spanning
    X +58..+83.56, protruding ~1.2mm behind the rear face (Z -1.20..0). Footprint measured
    from the rear view (approximate). Added to STEP/STL/SCAD, DXF layer CONNECTOR, side-profile
    DXF, reference + README; new rear-3D image.
    [lcd_centerdatum.dxf, lcd_cornerdatum.dxf, lcd_panel.scad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]
2026-06-17 Fix BL/BR lug outlines: preserve the gusset diagonal edge
    Bottom ears (BL/BR) were over-smoothed into symmetric rounded tabs; the real ears are
    gussets with a straight diagonal edge + rounded lobe. Re-traced at 2400 DPI with the
    diagonal preserved (no opening, fine simplification). Updated _ears.json, ear images,
    STEP/STL/SCAD/DXFs, overview + 3D images. TL/TR unchanged.
    [lcd_centerdatum.dxf, lcd_cornerdatum.dxf, lcd_panel.scad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]
2026-06-17 BL/BR lug outlines follow the real lobe curve (was chorded/boxy)
    Bottom ears were chorded across the round lobe (looked rectangular). Re-traced with gentle
    centerline erode + fine simplification so the outline follows the actual diagonal + round
    lobe. Updated _ears.json, ear images, STEP/STL/SCAD/DXFs, overview + 3D.
    [lcd_centerdatum.dxf, lcd_cornerdatum.dxf, lcd_panel.scad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]
2026-06-17 Round the module outline corners (R2.3) — was a sharp rectangle
    The LCD outline has rounded corners (R~2.3 measured from the drawing); modeled as a sharp
    rect before. Body now filleted R2.3 (STEP/STL), outline drawn as rounded rect in DXFs + SCAD.
    OUTLINE_R param exposed. Updated overview/3D images, reference, README.
    [lcd_centerdatum.dxf, lcd_cornerdatum.dxf, lcd_panel.scad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]
2026-06-17 Outline corners R0.5 (not R2.3 bezel radius); add BL corner notch/chamfer
    R2.3 was the inner bezel radius; the outer outline corners are near-sharp -> R0.5.
    BL corner chamfered (notch ~1.2mm, detected from the drawing). Params OUTLINE_R/BL_NOTCH
    exposed. Updated STEP/STL/SCAD/DXFs, overview/3D, reference, README.
    [lcd_centerdatum.dxf, lcd_cornerdatum.dxf, lcd_panel.scad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]
2026-06-17 Outline non-square at bottom-left (raised step + ramp), not a chamfer
    The BL is not a corner chamfer: the bottom edge is raised ~0.95mm (Y=-103.49) across the
    bottom-left ~17mm (X -83.56..-66), then ramps down to the full bottom (-104.44) by X=-63.8.
    Rebuilt the outline as a polygon with this step (replaces the fillet+chamfer); re-traced the
    BL ear to the raised bottom edge so it fuses. Corners R0.5. Updated STEP/STL/SCAD/DXFs,
    overview/3D, reference, README.
    [lcd_centerdatum.dxf, lcd_cornerdatum.dxf, lcd_panel.scad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]
2026-06-17 Restart: rebuild all geometry from a colour-cleaned trace
    Strip every non-geometry marking from the FRONT VIEW by colour (dimension
    lines, centerlines, green active-reference, header), rasterize the clean
    outline, then trace outline + 4 lug ears + holes from that image and
    self-calibrate to the 167.12x208.88 outline.
    - geometry.json: single source of truth (outline, ears, holes, bezel, Z, connector)
    - body = traced outline (R0.5, bottom-left raised step + ramp), full 2.60mm
    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
    [lcd_centerdatum.dxf, lcd_cornerdatum.dxf, lcd_lugs.csv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]
2026-06-27 Add two photo-frame mounting brackets (182x242, view-centered)
    C-channel top/bottom brackets that friction-fit a 182x242 photo-frame inner
    cavity and press the LCD onto the glass. Centers the ACTIVE area (panel shifted
    +1.30,+0.89), so gaps are 15.67 (top) / 17.45 (bottom). Ear-clearance pockets
    for the lug tabs (top TL+TR, bottom BL+BR). build_brackets.py (cadquery) +
    brackets.scad (parametric) + verify_brackets.py assembly/section images.
    [bracket_bottom.step, bracket_bottom.stl, bracket_top.step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]
2026-06-27 Brackets: LCD flat on glass (drop front lip, add 0.15mm rear-shelf preload)
    Per request to keep the LCD as close to the glass as possible with light
    pressure: remove the 1.0mm front lip (which held the screen 1mm off the glass)
    so the screen now sits flat on the glass. A solid rear shelf set 0.15mm proud
    of the panel rear (PRELOAD) is pressed forward by the frame backing, holding
    the LCD lightly against the glass. Updated build_brackets.py, brackets.scad,
    verify_brackets.py section view, README.
    [bracket_bottom.step, bracket_bottom.stl, bracket_top.step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]
2026-06-27 Brackets: ear pockets to back face (press from behind) + thin test STLs
    Printed top bracket fit but only seated flipped, reversing the press. The lug
    ears are on the LCD rear, while ear pockets were cut on the front, forcing a
    flip that put the pressing shelf on the glass side. Move ear pockets to the
    back face (EAR_ON_BACK) so the bracket fits one way only and the rear shelf
    presses the LCD from behind onto the glass. Add 5mm-thick thin test-print
    variants (bracket_top_thin.stl, bracket_bottom_thin.stl) for fast fit checks.
    [bracket_bottom.step, bracket_bottom.stl, bracket_bottom_thin.stl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]
2026-06-27 Brackets: ear pockets back to FRONT face (lugs are on LCD front, ~0.25mm recessed)
    Correction: the lug ears are on the LCD FRONT (recessed ~0.25mm toward the
    glass), not the rear. Revert ear-clearance pockets to the front face
    (EAR_ON_BACK=False). Front ears + front pockets shape-key the part so it only
    seats ears-toward-glass, keeping the press shelf at the back -> still pushes the
    LCD from behind onto the glass. Press/shelf geometry unchanged. Updated scad,
    verify section annotation, README.
    [bracket_bottom.step, bracket_bottom.stl, bracket_bottom_thin.stl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]
2026-06-28 Brackets: fix slot too narrow + shallow ear pockets + MIRROR_X test
    Fit-test of the thin top exposed two bugs:
    - Panel slot was 2.45mm (shelf TH-PRELOAD), narrower than the 2.60 LCD -> panel
    could not enter. Replace PRELOAD with SLOT_CLR=0.15: slot = TH+SLOT_CLR=2.75,
    shelf now sits entirely BEHIND the LCD; frame backing presses bracket->LCD->glass.
    - Ear pockets were 2.0mm deep; ears are recessed only ~0.25mm -> EAR_Z=0.7 shallow,
    near-flush.
    Add MIRROR_X toggle + bracket_top_thin_mir.stl (X-mirrored thin top) to settle
    the handedness question empirically. Updated scad, verify, README.
    [bracket_bottom.step, bracket_bottom.stl, bracket_bottom_thin.stl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]
2026-06-28 Brackets: fix ear-pocket offsets, finalize for production
    Audit (incl. adversarial verify workflow) found two real bugs in ear-pocket
    placement, now fixed:
    - Pockets were not X-shifted (panel is view-shifted +1.30 in X) -> ~0.2mm
    clearance on one side. Now placed at each ear's actual frame bbox (X+SHIFT_X,
    Y+SHIFT_Y, mirror-aware), giving 1.5mm clearance all round.
    - TL is a left-edge ear (tops below the top edge); the old code placed its
    pocket above the ear (missed it). Generic frame-bbox logic now covers it.
    Pockets cut shallow on the FRONT (Z 0..0.7) per the ~0.25mm-recessed front
    tabs; rear shelf untouched. Drop the confusing stale bracket_top_thin_mir.stl
    (+ README refs); keep M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
    [bracket_bottom.step, bracket_bottom.stl, bracket_bottom_thin.stl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]
2026-06-28 Brackets: add 'BACK' orientation deboss + orientation docs/figure
    Geometry verified correct (presses from behind); the only issue was installing
    the near-symmetric part flipped. Deboss 'BACK' into the flat rear face (the
    print-bed face = frame-backing face); the opposite open/ear-pocket face goes to
    the glass. Add brackets_orientation.png and an Orientation section (print the
    BACK face on the bed, pockets up = support-free; assemble pocket-face to glass).
    Mirror the label into brackets.scad. Both full + thin remain single valid solids,
    all STL watertight.
    [bracket_bottom.step, bracket_bottom.stl, bracket_bottom_thin.stl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]
2026-06-28 Brackets: mirror X to match the physical panel (datasheet front view is mirrored)
    User confirmed (holding the real panel) the front-view lug layout is mirrored
    left-right vs the datasheet trace: the prominent angled lug is top-RIGHT, not
    top-left. The datasheet FRONT VIEW is drawn mirrored relative to the physical
    part. Set MIRROR_X=True (build_brackets.py + brackets.scad) so the ear pockets,
    panel shift and outline match the real panel.
    Also reworked brackets_assembly.png into a true FRONT view: brackets drawn
    behind (light), lug ears drawn on top (solid + hole markers) so the front-side
    ears are clearly visible and correctly handed. README handedness note added.
    Both full + thin remain s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
    [bracket_bottom.step, bracket_bottom.stl, bracket_bottom_thin.stl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]
2026-06-28 Add passe-partout (mat) drawing + DXF: 180x240x1.4, 45deg bevel window = active screen
    Centred 45-degree-bevel window revealing only the active screen (147.456 x
    196.608) in a 180x240x1.4 mat. Active is centred at the frame centre, so the
    window is centred (equal borders 16.27 L/R, 21.70 T/B front). Bevel flares
    1.4mm/edge toward the LCD (back window 150.26 x 199.41). passepartout.py emits a
    dimensioned drawing (images/passepartout.png) + passepartout.dxf (BOARD /
    WINDOW_FRONT / WINDOW_BACK layers); OVERLAP param to hide the screen edge.
    [passepartout.dxf]
2026-06-28 Passe-partout: flip bevel to open toward the glass (screen edge on the LCD side)
    Bevel was on the wrong side (standard picture-mat: small opening at the glass).
    For a screen the limiting edge should sit at the screen plane: put the
    screen-sized opening (147.46 x 196.61) on the LCD-facing back face and flare the
    45deg bevel toward the glass/viewer. Glass-face opening 150.26 x 199.41 (borders
    14.87/20.30); LCD-face borders 16.27/21.70. BEVEL_TOWARD param ('glass' default,
    'lcd' for standard). DXF layers WINDOW_SCREEN / WINDOW_GLASS.
    [passepartout.dxf]
2026-06-28 Passe-partout: redo drawing as a hand-marking guide (ruler/pencil)
    Ruler grid (mm, origin bottom-left), the screen window as the bold mark line
    with corner coordinates, all four edge border offsets (16.27 L/R, 21.70 T/B),
    red edge tick marks where to lay the ruler, a how-to-mark step list and bevel
    section. For marking a real board with a ruler + pencil before bevel-cutting.
